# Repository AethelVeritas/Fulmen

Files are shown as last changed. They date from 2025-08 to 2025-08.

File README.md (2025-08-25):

# Fulmen
A small wireless low-profile split keyboard.

jlc_blue

Shield: [][cc-by-nc-sa]

This work is licensed under a
[Creative Commons Attribution-NonCommercial-ShareAlike 4.0 International License][cc-by-nc-sa].

[][cc-by-nc-sa]

[cc-by-nc-sa]: http://creativecommons.org/licenses/by-nc-sa/4.0/
[cc-by-nc-sa-image]: https://licensebuttons.net/l/by-nc-sa/4.0/88x31.png
[cc-by-nc-sa-shield]: https://img.shields.io/badge/License-CC%20BY--NC--SA%204.0-lightgrey.svg

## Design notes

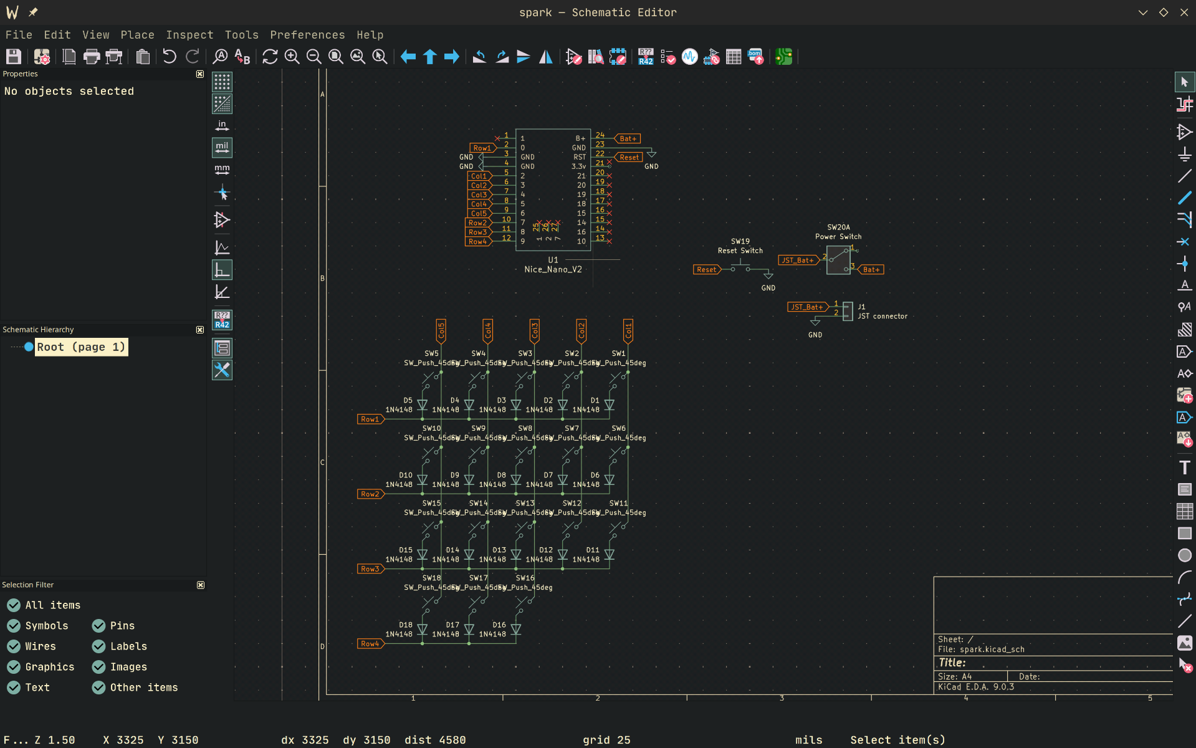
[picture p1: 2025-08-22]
pics/schematic.png

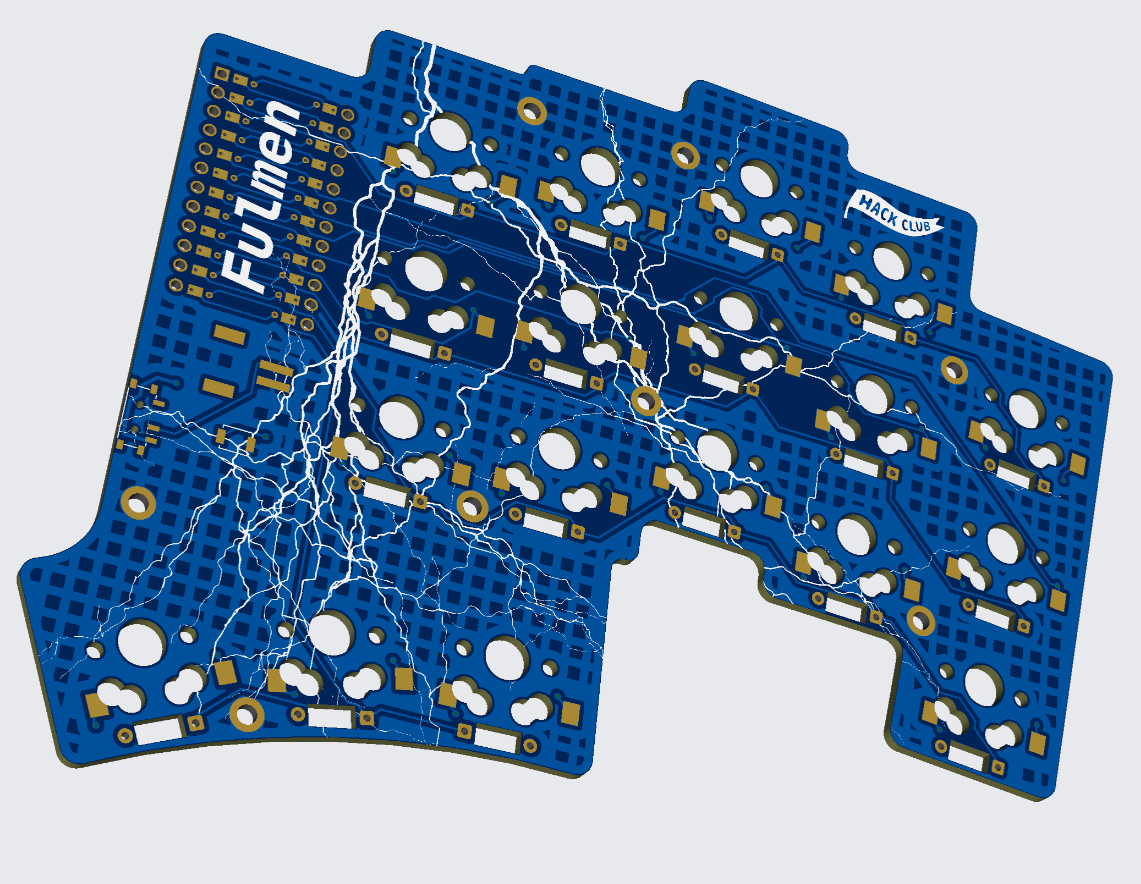
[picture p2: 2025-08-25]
pics/jlc_blue.png

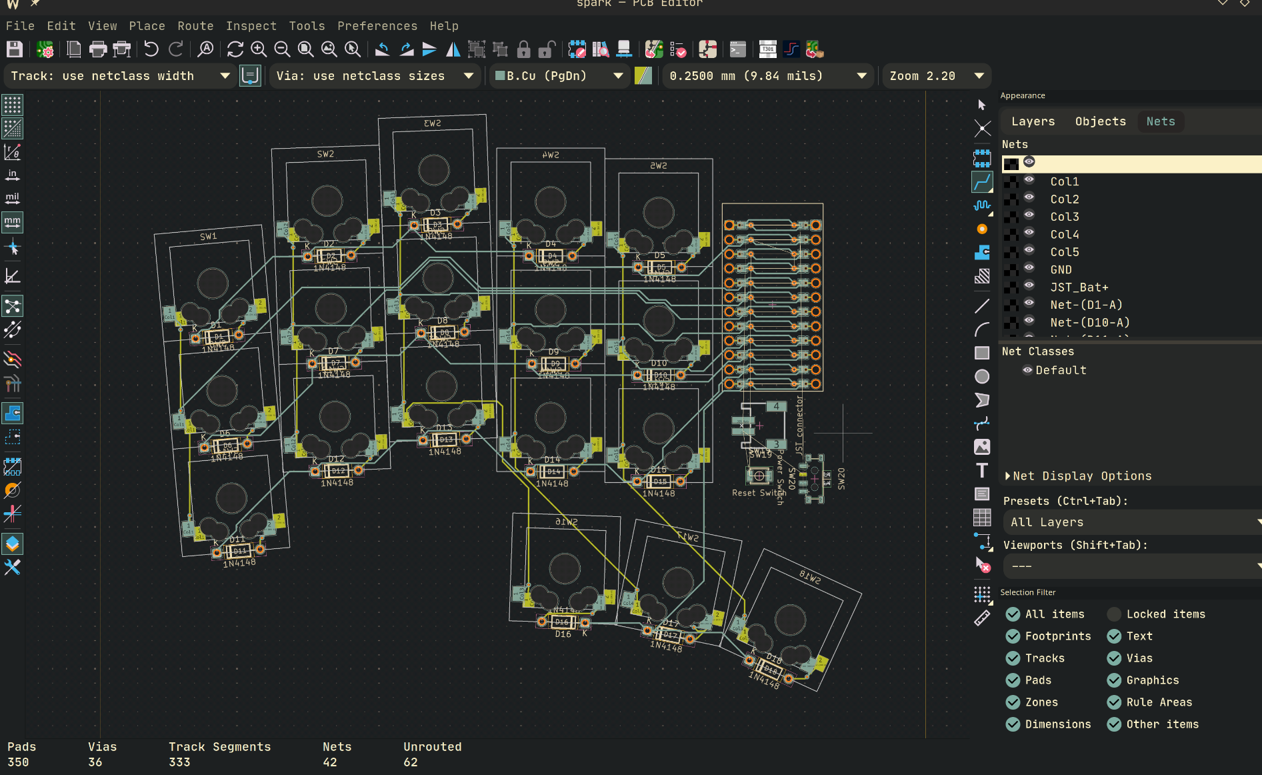
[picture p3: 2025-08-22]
pics/routing_progress.png

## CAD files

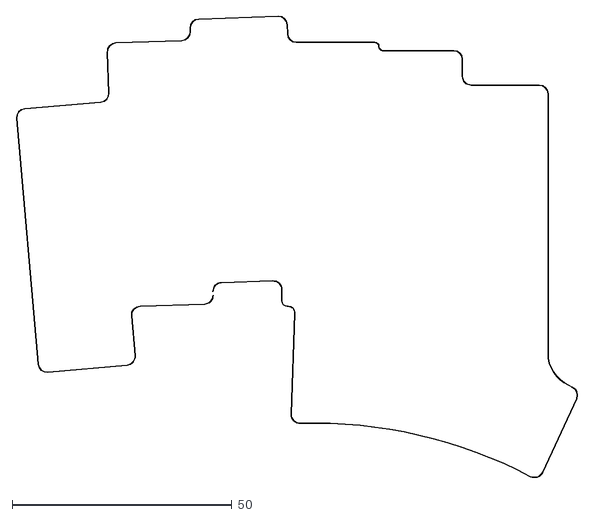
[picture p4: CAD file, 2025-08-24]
PCB/PCB Outline.dxf
127.9 x 105.0

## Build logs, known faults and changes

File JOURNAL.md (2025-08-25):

---
Title: Fulmen 
Author: AethelVeritas
Description: A small wireless low-profile split keyboard.
Created On: 10/08/2025
Total Time Spent: 26h 
---

## 10/08/2025
**Time Spent: 6h 20m**

Firstly, I did some research and decided on some constraints/goals:
1. Must be wireless.
2. Must use KS33 switches (Nuphy ones most likely), as they are cheaper than Choc switches.
3. Must be low-profile. I won't be able to make it very low-profile, not as much as I could have if I used Chocs, but I still want it to look and feel sleek. 
4. Must have at least 3 thumb keys, but not more than 5 columns. I have built a handwired 3x6 build, and while I did enjoy it, I want to try out 3 columns.
5. Hotswappable and reversible PCB. After how much time I wasted on mirroing components for my last trial design, I want something simpler now. The disadvantage would be of course that I would get less PCBs for the price, but oh well it is what it is.

Then, I started messing around with [Ergogen](https://ergogen.ceoloide.com/). I had built the layout for my previous handwired build using this tool, but I had forgetten a lot of things, so I took another look at [FlatFootFox's amazing guide](https://flatfootfox.com/ergogen-introduction/), as well as the config.yaml of the [Avocado](https://github.com/auryn31/avocado) by Auryn. It took a couple of hours, but after messing around with it for some time I got a config I thought looked and felt pretty nice. So I printed out several plates and tested them  with some MX switches and keycaps I had lying around. One thing I really did struggle with was the outline: I tried to somehow combine two outlines (the switch cutouts as well as some cutouts that were 1mm bigger for the switch clips)into one .dxf, but I did not have any success. Eventually I just imported both into Onshape and positioned them there, which was tedious, but such is life. I probably won't make the final version in Ergogen: I find it easier in Onshape. The only thing I really want to use Ergogen for is positioning the switches. 
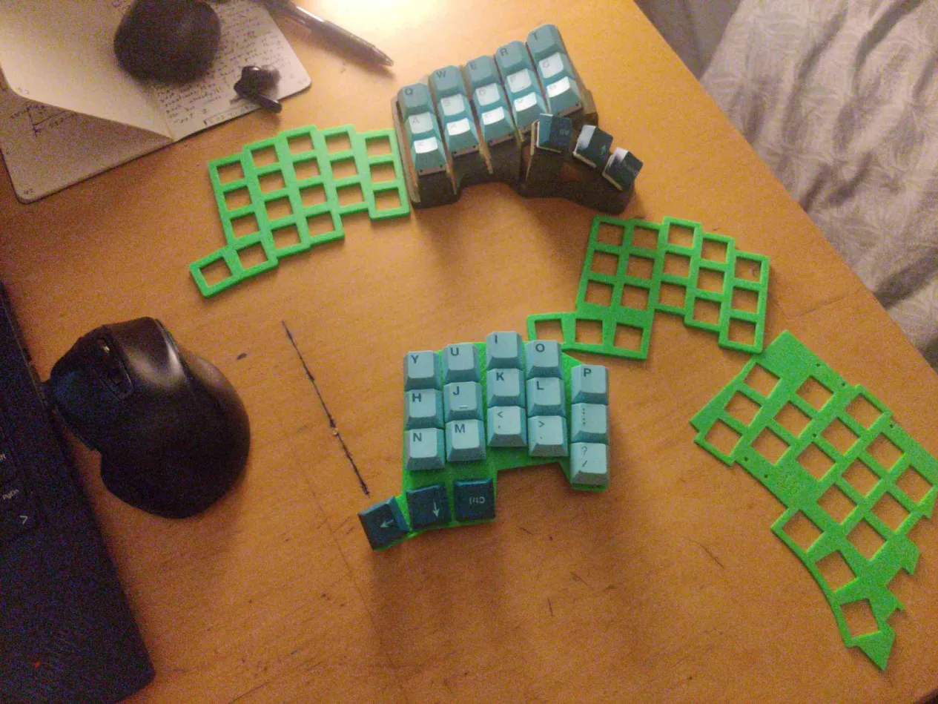
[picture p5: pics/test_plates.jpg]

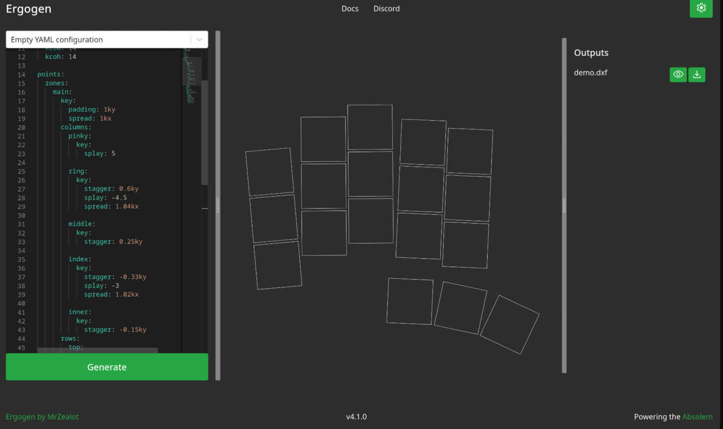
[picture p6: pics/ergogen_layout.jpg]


## 14/08/2025
**Time Spent: 2h 40m**

Struggled quite a bit with figuring out how to make 3D models of the custom KS33 footprint I used from [this](https://github.com/ceoloide/ergogen-footprints) render properly in KiCAD. Turns out it was all because I used "~/path to file" instead of "/home/username/path to file", so yeah I'm dumb. Had to use a custom 3D model for the KS33 from Grabcad, as Ai03's library only has the hotswap 3d model. And I obviously had to adjust the offset and rotation of both models to make them render properly. I especially struggled with the hotswap 3D model: I'd keep going and changing one individual model in the footprint editor, align it properly, add the offset and rotation values to ergogen, download the PCB and low and behold it wouldn't work. After 2h of messing with this damn problem I gave up. I'll just have to design the case another way or edit the values for every model for every switch model manually, which will be tedious but not impossible. Right now the focus is the PCB, as I can modify the case later as I own a 3D printer.
After all that crap, I installed [marbastlib](https://github.com/ebastler/marbastlib), which is an amazing library containing a plethora of keyboard related symbols, 3D models, and footprints and then called it a day.
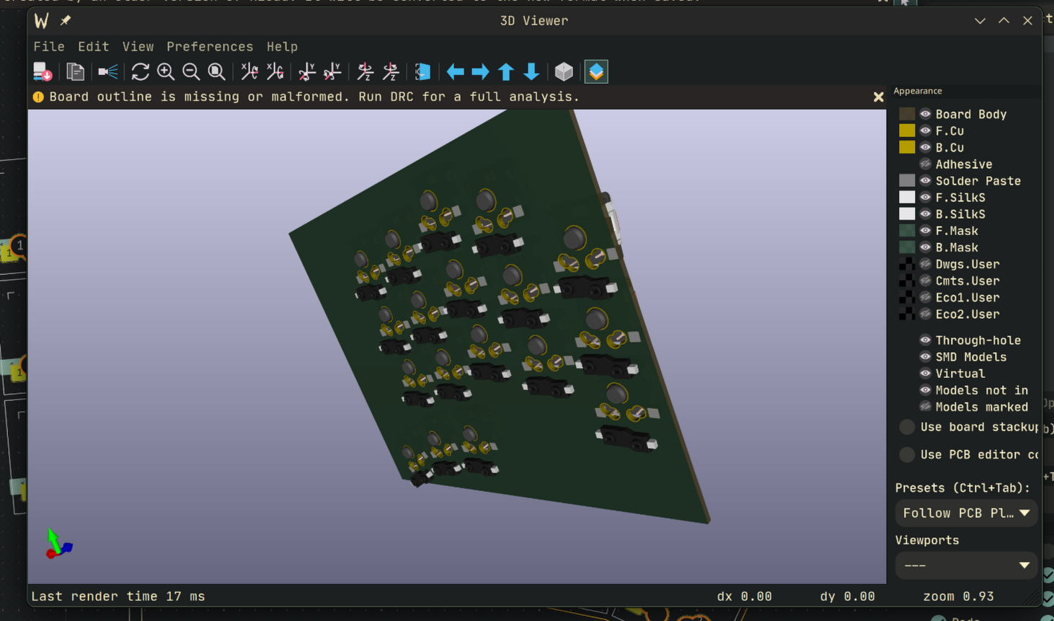
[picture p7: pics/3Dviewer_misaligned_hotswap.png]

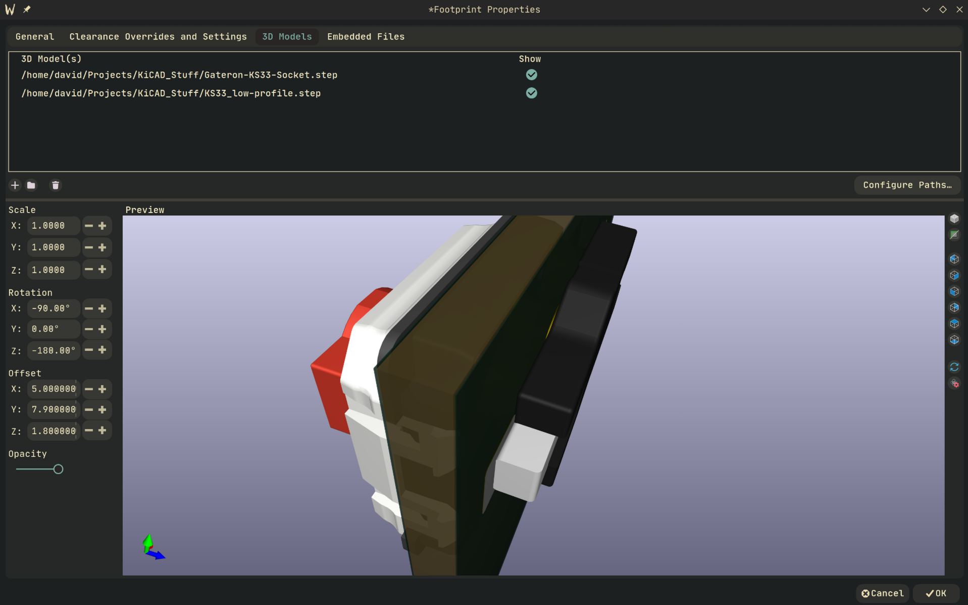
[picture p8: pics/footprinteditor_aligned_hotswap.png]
 

## 15/08/2025
**Time Spent: 3h 40m**

While manually assigning schematic references such "SW1" to the switches, I came across what is in my opinion an extremely cool feature: if you double click on a footprint, under the "Update from library button" there is a button called "Change footprint", and clicking that opens up a menu which allows you to change either that specific fooptrint or all footprints of that type from the board with another footprint. This would have been insanely helpful when I designed Quaero, my first PCB keyboard. I made a copy of the standard 1N4148 diode footprint and edited it so that there is a small cutout, slightly larger than the diode itself, right under the diode. After doing so, I used the aforesaid feature to update all of my diodes. I think I saw/heard somewhere about people pressing their THT diodes into the LED cutouts that come with boards to make the whole board more low-profile, and I'm thinking it won't hurt to tryout this idea for myself. Because I'm using hotswap sockets this will not really reduce the height of my board, but well it's a good idea to include the cutouts anyway. 
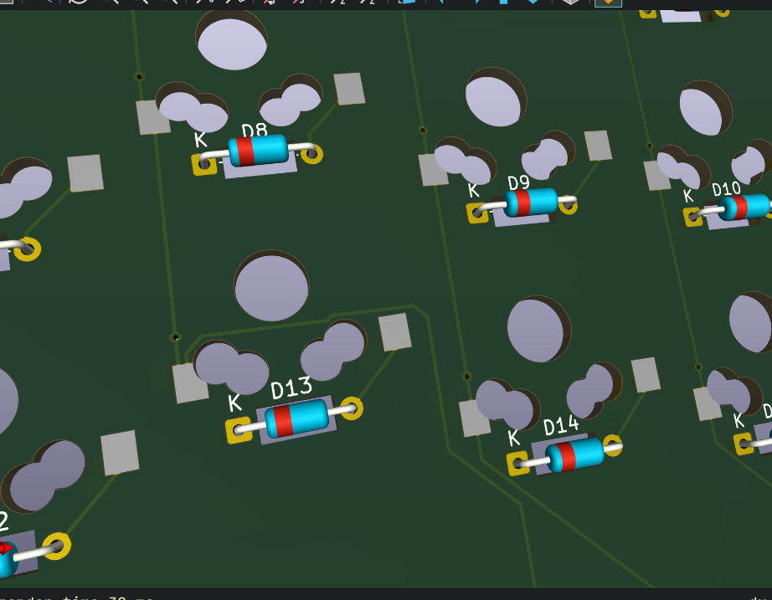
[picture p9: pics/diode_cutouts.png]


I also did part of the routing:
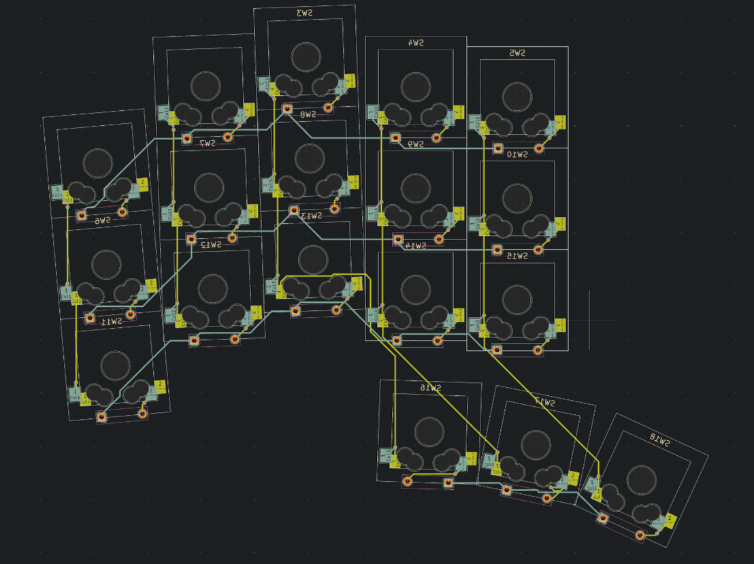
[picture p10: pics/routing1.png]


## 19/08/2025
**Time Spent: 3h**

Did a lot of cleaning up and double-checking: decided what button to use for the reset and power switches, got the footprints, made them reversibe (kinda), and most importantly troubleshooted the damn MCU. The problem was that the symbol for the MCU (which I got from marbastlib), had the pin assignments descending from 1 to 12 on the left, and then again from the top descending from 13 to 24, while all the reversible footprint I found had the pins descending from the top on the left and then ascending from the bottom on the right. Turns out that it's common practice to do the latter, and not the former. At first I tried to edit the pin assignments of the footprint, only to realise after some time that I can just swap the symbol (yes I'm dumb). Wasted a lot of time on this issue. 
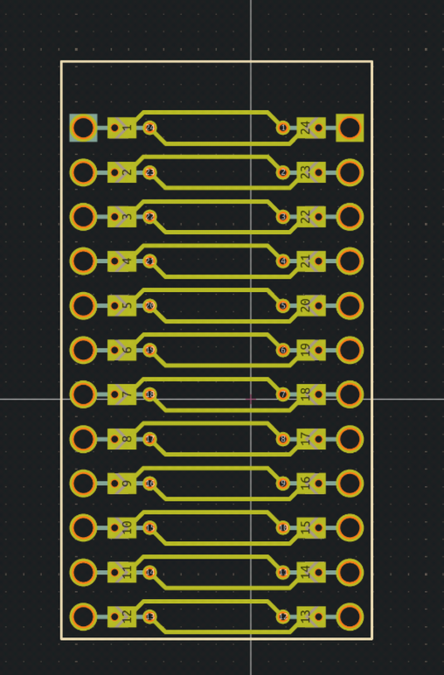
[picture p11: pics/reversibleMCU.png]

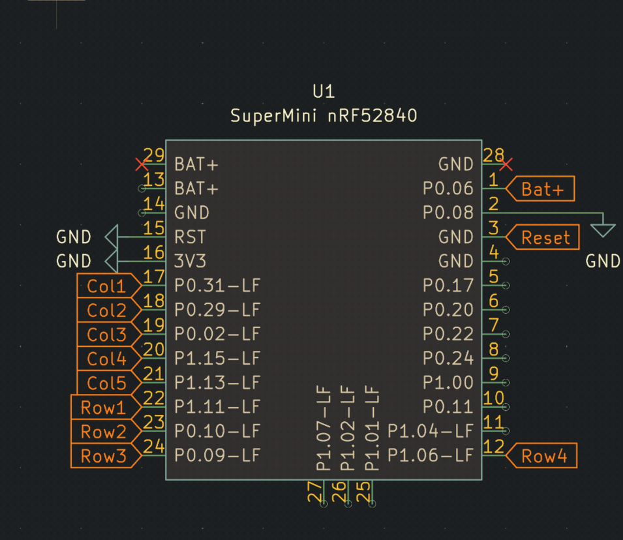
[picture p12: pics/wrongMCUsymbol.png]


## 24/08/2025
**Time Spent: 7h**

Finished routing, and now I've got like 496 errors in the DRC lol. Most of them are from the reversible footprints though: intersecting cutout holes and all that. 
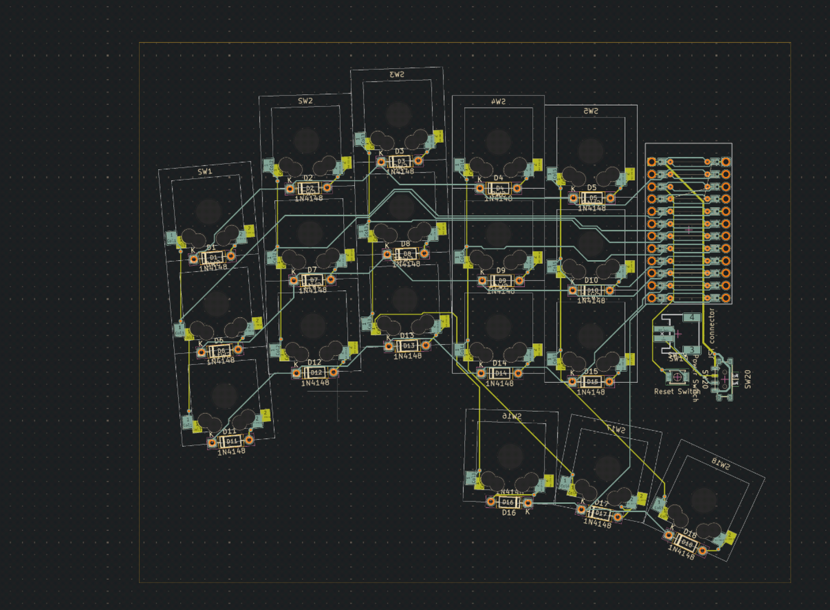
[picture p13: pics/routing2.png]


Also made the outline. I first made sure everything I needed was on the proper layer (some outlines such as those of the MCU and the switch were on the B.Courtyard layer instead of the proper silkscreen one), and then I exported said layer as a .dxf (using the "Plot" tool) and then imported that into Onshape. Now what I did was I fixed dxf I imported in a sketch, and then added an offset variable and created an offset for the whole thing. Then I selected the stuff I had imported, deleted that, and then exported the resulting outline as .dxf. But I just realized that what I did was extremely stupid: I could have just left the imported .dxf on one sketch, then created a new sketch on top of that, used the former as reference for the outline, and then just exported the sketch containing the outline. 

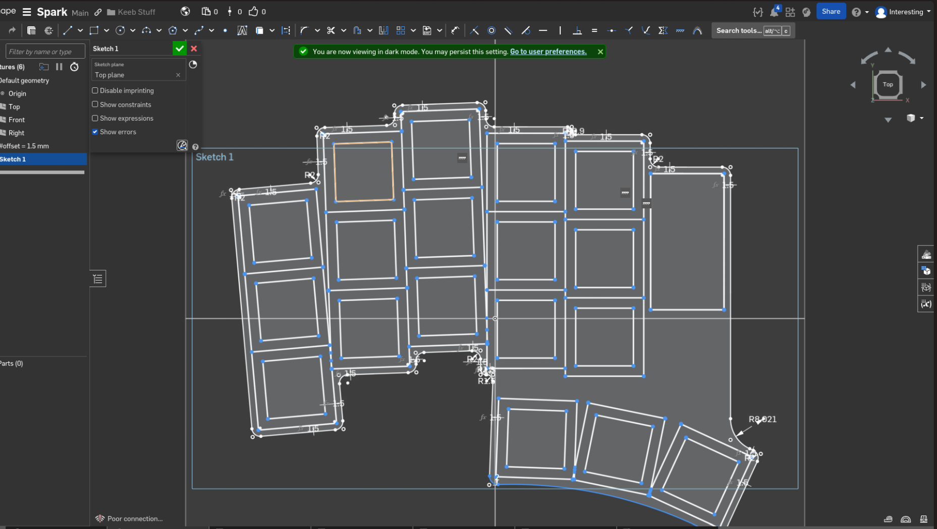
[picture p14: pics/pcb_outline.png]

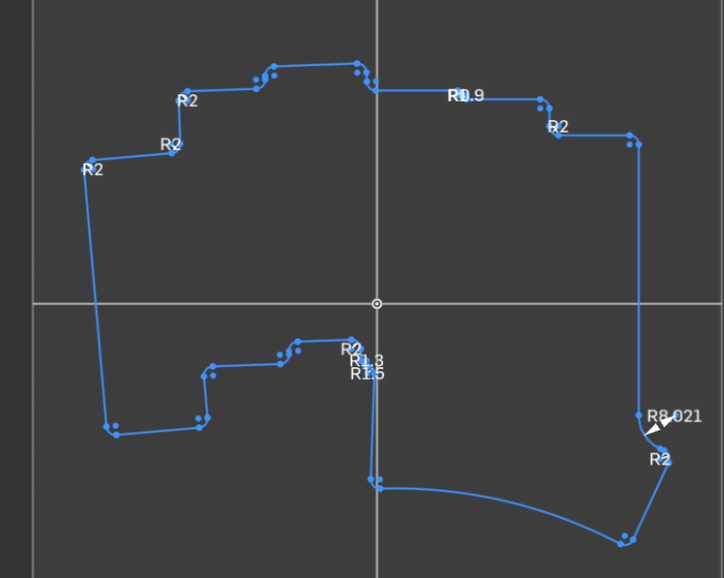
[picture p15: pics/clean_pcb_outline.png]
 
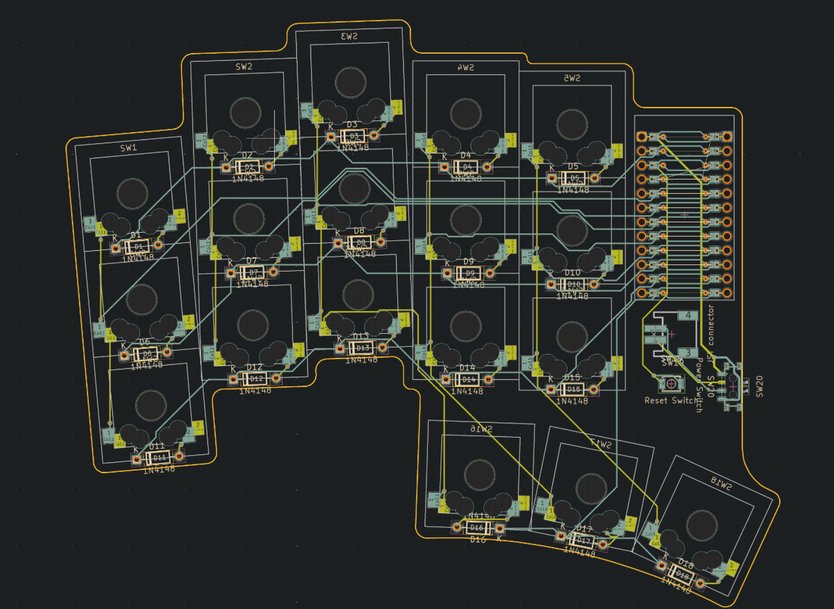
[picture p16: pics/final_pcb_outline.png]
 

Added ground fill and mounting holes as well.
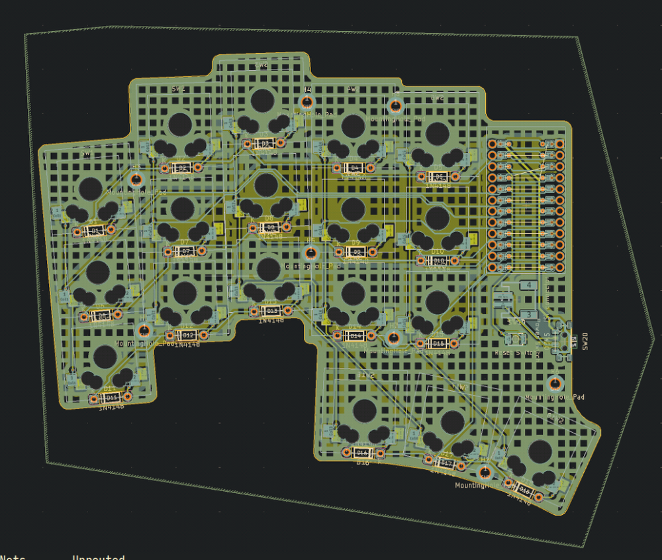
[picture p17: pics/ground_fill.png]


Ok now to deal with silkscreen and graphics and all that. I've decided to rename the whole keyboard "Fulmen" (Latin for lighnting). Should encompass the idea of fast pretty well, plus I can find cooler svgs for that.

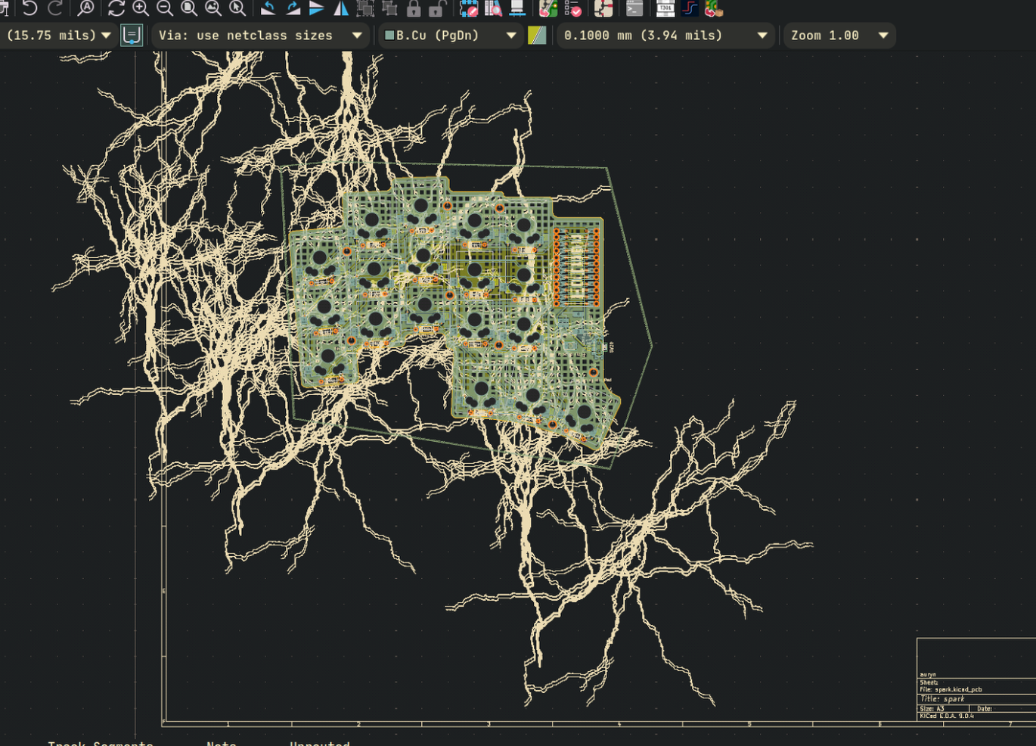
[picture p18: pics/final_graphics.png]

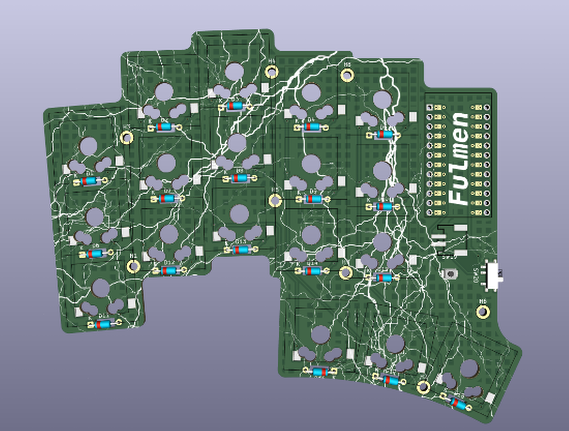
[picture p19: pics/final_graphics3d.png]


I'm honestly surprised my T14 laptop didn't just give up...all of these graphics were demanding as hell on my integrated GPU.

## 25/08/2025 
**Time Spent: 3h 20m**

I spent a lot of time troubleshooting the gerbers: I would upload the zip to jlcpcb and viewer would just get stuck at 96%. After emailing them and finding out that it's because my silkscreen extended beyond the edge.cuts outline (I thought that it would just automatically be ignored/clip), I first tried to somehow remove every silkscreen that's not inside the edge.cuts directly from KiCAD, so I asked around and spent like 2h trying to do that. Then I moved on to inkscape, where I didn't succeed either. Then finally,I said scratch that, let me try with fewer graphics. Turns out that it can extend beyond the edge.cuts, but just not too much, so yeah now I finally have a decent looking end result. 

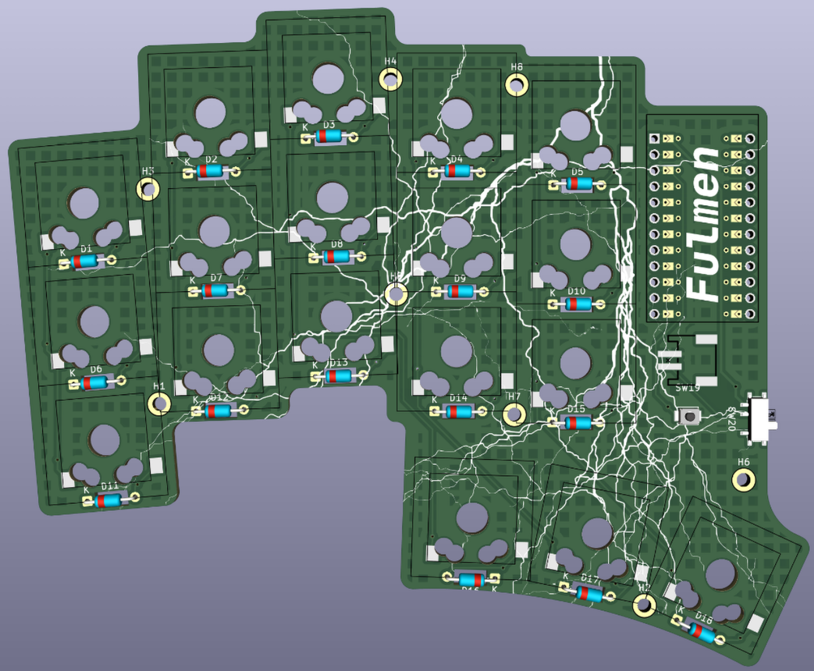
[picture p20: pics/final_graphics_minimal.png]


I also changed all the references for the default footprints such as the diodes from the silkscreen layer to F.Mask, so that they wouldn't show up on the final board. Didn't know you could edit the properties of multiple items in a selection before, but turns out you can do that by going to the toolbar, then "View", and then enabling the "Properties" panel.

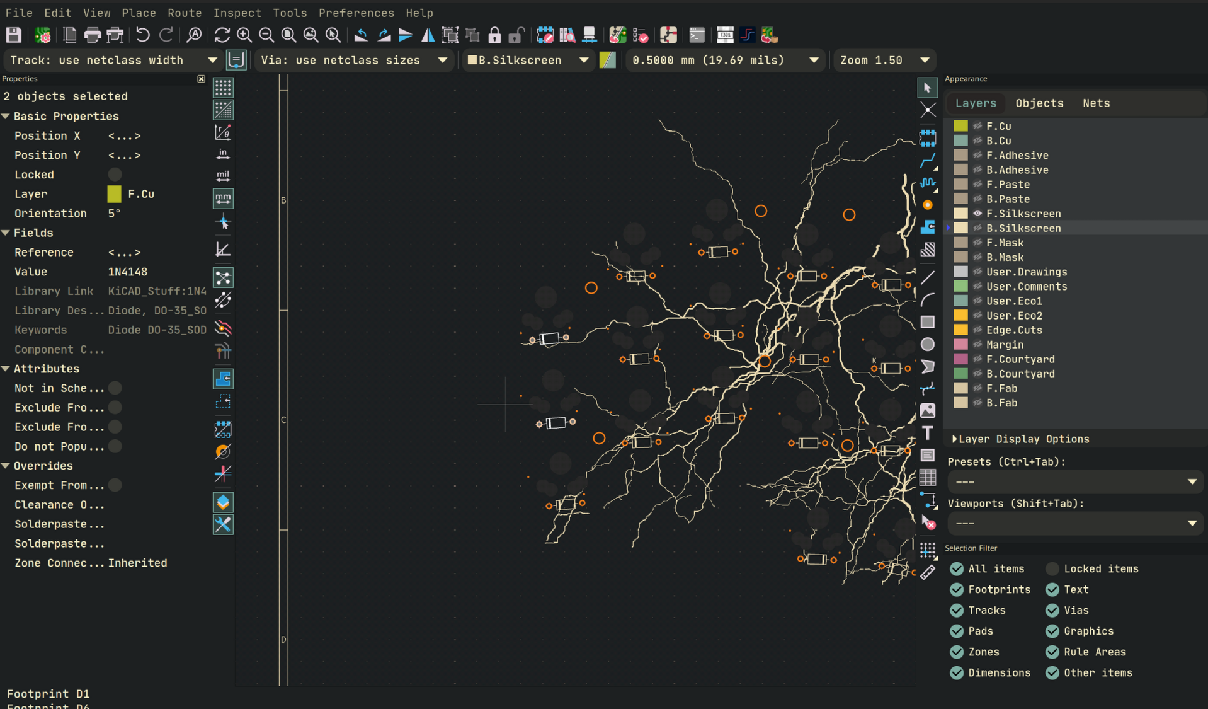
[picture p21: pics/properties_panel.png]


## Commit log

2025-08-19 Updated JOURNAL.md and added PCB files
    [spark.kicad_pcb, spark.kicad_sch]
2025-08-22 Routed everything
    [spark.kicad_pcb, spark.kicad_sch]
2025-08-24 Finished PCB, renamed to Fulmen
    [PCB Outline.dxf, fulmen.kicad_sch, spark.kicad_pcb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]
2025-08-25 Final version, silkscreen still giving errors though.
    [Fulmen.kicad_sch]
2025-08-25 deletions and renaming of fulmen to Fulmen
    [fulmen.kicad_sch]
2025-08-30 Updated PCB because some traces were cut by diode cutouts

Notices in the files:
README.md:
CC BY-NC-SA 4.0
